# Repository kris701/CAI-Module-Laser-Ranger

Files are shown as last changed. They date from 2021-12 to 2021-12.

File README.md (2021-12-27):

# CAI-Module-Laser-Ranger
This is a project about making an extension module for my Snapmaker Original printer. This is also an extension to [another of my projects](https://github.com/kris701/CAI), and is directly connected to it. It is also designed to be mounted on my [toolhead extension project](https://github.com/kris701/SnapMaker-Toolhead-Extensions).
The purpose of this module is to making calibration of the Snapmaker Laser module easier, since it can be a bit of a pain to calibrate it every time you need to use it. Instead, this is a system where a little screen displays how far above the bed that the module is. This makes it a lot easier to calibrate is, as it removes the need to use that little calibration paper that comes with the printer.

<p align="center">
  
  
</p>

The system consists of a little OLED screen, a infrared proximity sensor and two buttons to calibrate it. The buttons can be held down, to move the little triangle in the display up or down. The last set calibration value is saved in the EEPROM of the Arduino Nano that controls it, so that its not lost when the power goes off.

<p align="center">
  
  
</p>

This then makes it so that you only really have to calibrate it once (with the calibration paper), and then you can just use the ranger module from there on out.

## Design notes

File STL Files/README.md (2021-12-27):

## Print Parts
### Screen Module
| |  |  |
|:---:|:---:|:---:|
| *Main Body* | *Lid* | *Screen Holder* |

### Sensor Module
| SensorModule_MainBody | SensorModule_Lid | SensorModule_Cover |
|:---:|:---:|:---:|
| *Main Body* | *Lid* | *Senspr Cover* |

The parts are put together with some M3 screws and bolts that i had.

## Printer settings

The config for a SnapMaker Original can be found under "Printing Config"

General config:

|Setting|Value|
|:---:|:---:|
| Layer Height |0.2mm |
| Top Thickness |0.8mm |
| Infil |35% |

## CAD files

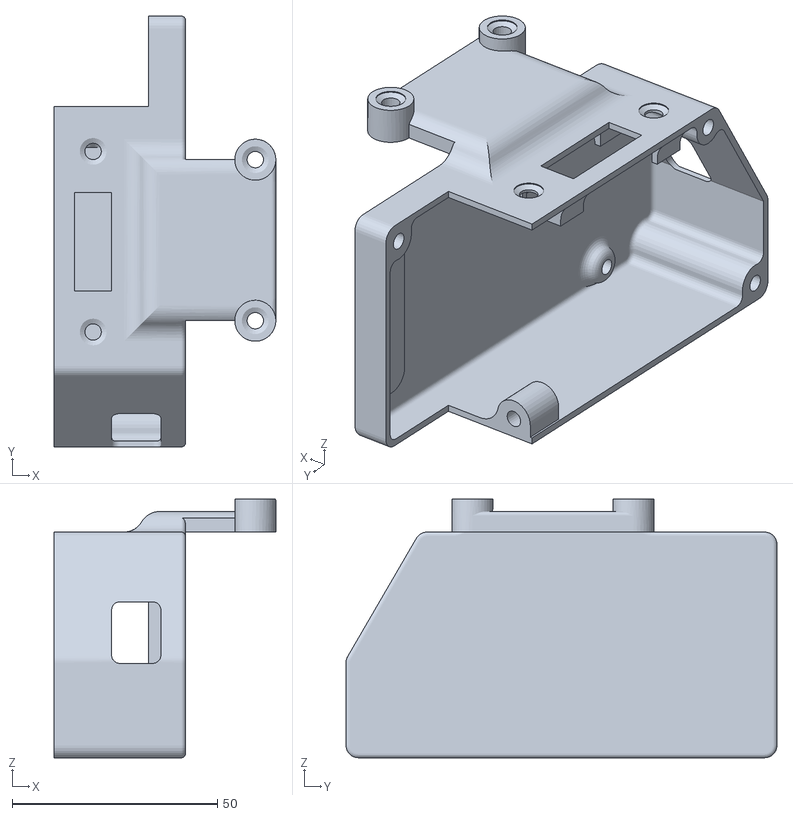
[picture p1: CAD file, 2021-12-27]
STL Files/ScreenModule/ScreenModule_MainBody.stl
54.0 x 105.0 x 63.0

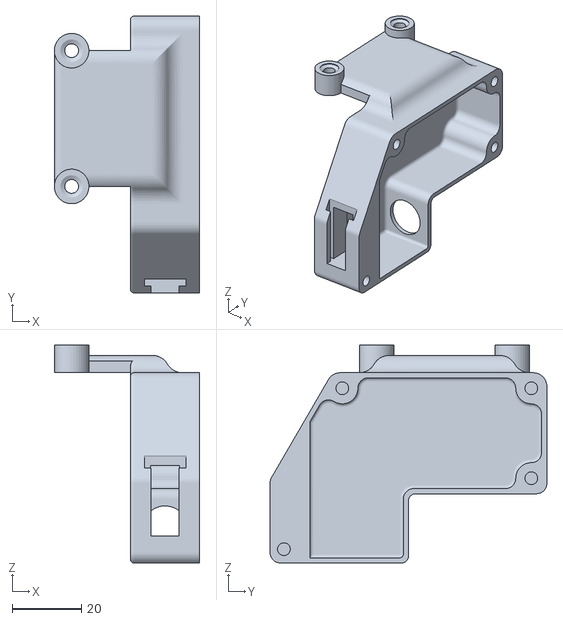
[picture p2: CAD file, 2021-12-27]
STL Files/SensorModule/SensorModule_MainBody.stl
42.0 x 80.0 x 63.0

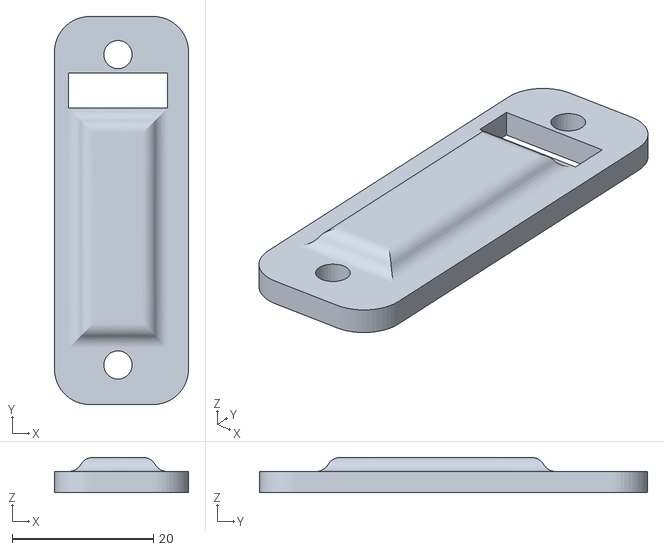
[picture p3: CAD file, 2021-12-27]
STL Files/ScreenModule/ScreenModule_ScreenHolder.stl
19.0 x 55.0 x 5.00

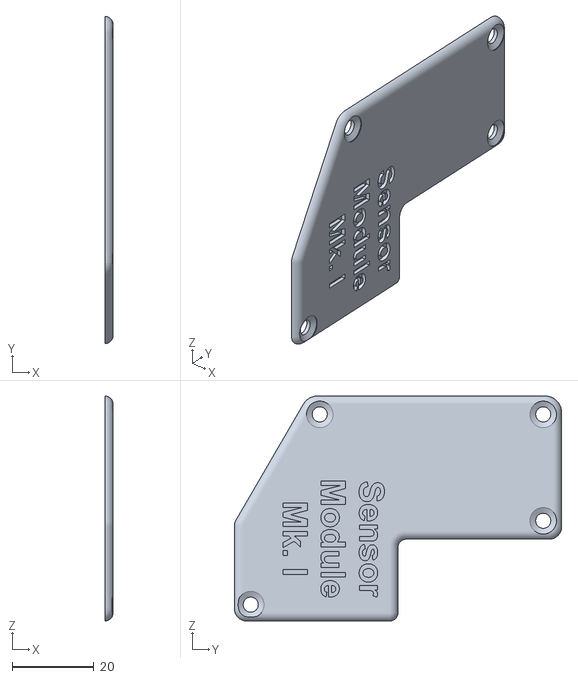
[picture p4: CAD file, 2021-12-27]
STL Files/SensorModule/SensorModule_Lid.stl
2.00 x 80.0 x 55.0

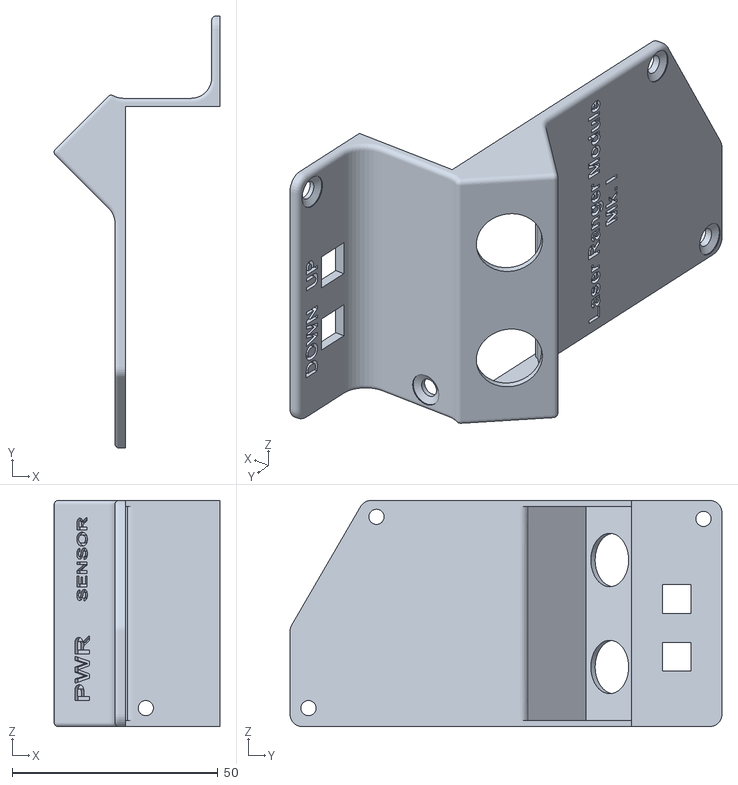
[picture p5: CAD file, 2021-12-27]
STL Files/ScreenModule/ScreenModule_Lid.stl
40.3 x 105.0 x 55.0

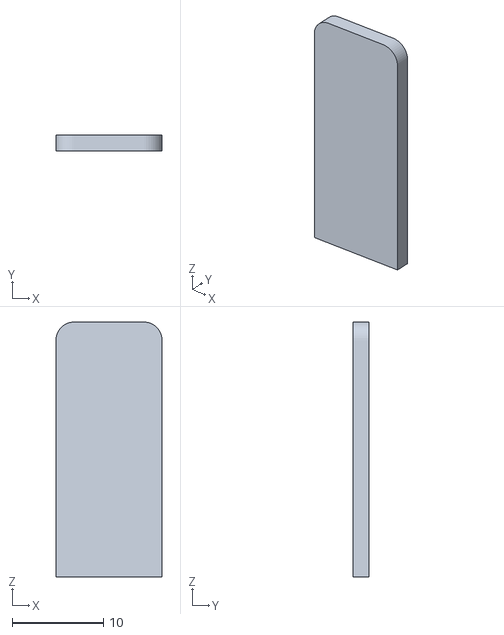
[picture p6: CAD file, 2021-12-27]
STL Files/SensorModule/SensorModule_Cover.stl
11.6 x 1.80 x 27.9

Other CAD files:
3D Models/RangerModuleCaseV1 v94.f3z

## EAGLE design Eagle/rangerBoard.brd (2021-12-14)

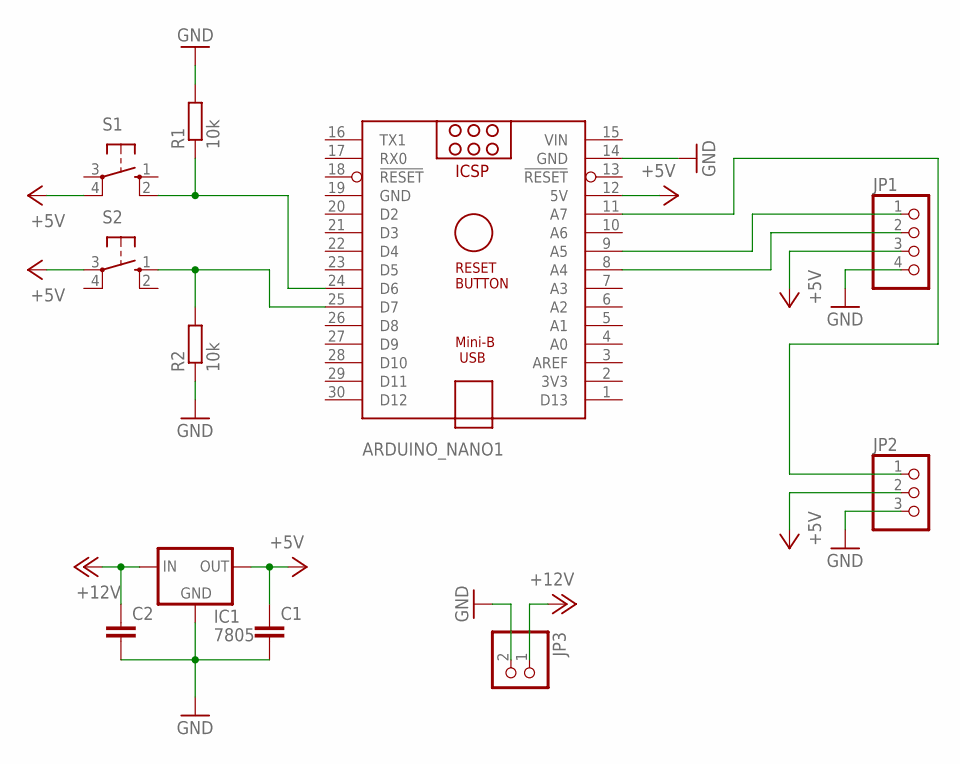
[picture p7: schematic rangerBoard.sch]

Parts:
ARDUINO_NANO1: ARDUINO_NANO
C1, C2: C5/7.2; C5B7.2
IC1: 7805; 78XXL
JP1: PINHD-1X4; 1X04
JP2: PINHD-1X3; 1X03
JP3: PINHD-1X2; 1X02
R1, R2: 10k; 0204/7
S1, S2: 10-XX; B3F-10XX

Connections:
+5V: ARDUINO_NANO1.12 (5V), C1.1, IC1.OUT, JP1.3, JP2.2, S1.4 (P1), S2.3
+12V: C2.1, IC1.IN, JP3.1
GND: ARDUINO_NANO1.14 (GND), ARDUINO_NANO1.19 (GND), C1.2, C2.2, IC1.GND, JP1.4, JP2.3, JP3.2, R1.2, R2.1
unnamed: ARDUINO_NANO1.24 (D6), R1.1, S1.2 (S1)
unnamed: ARDUINO_NANO1.25 (D7), R2.2, S2.1 (S)
unnamed: ARDUINO_NANO1.11 (A7), JP2.1
unnamed: ARDUINO_NANO1.8 (A4), JP1.2
unnamed: ARDUINO_NANO1.9 (A5), JP1.1
VIN: ARDUINO_NANO1.15 (VIN)

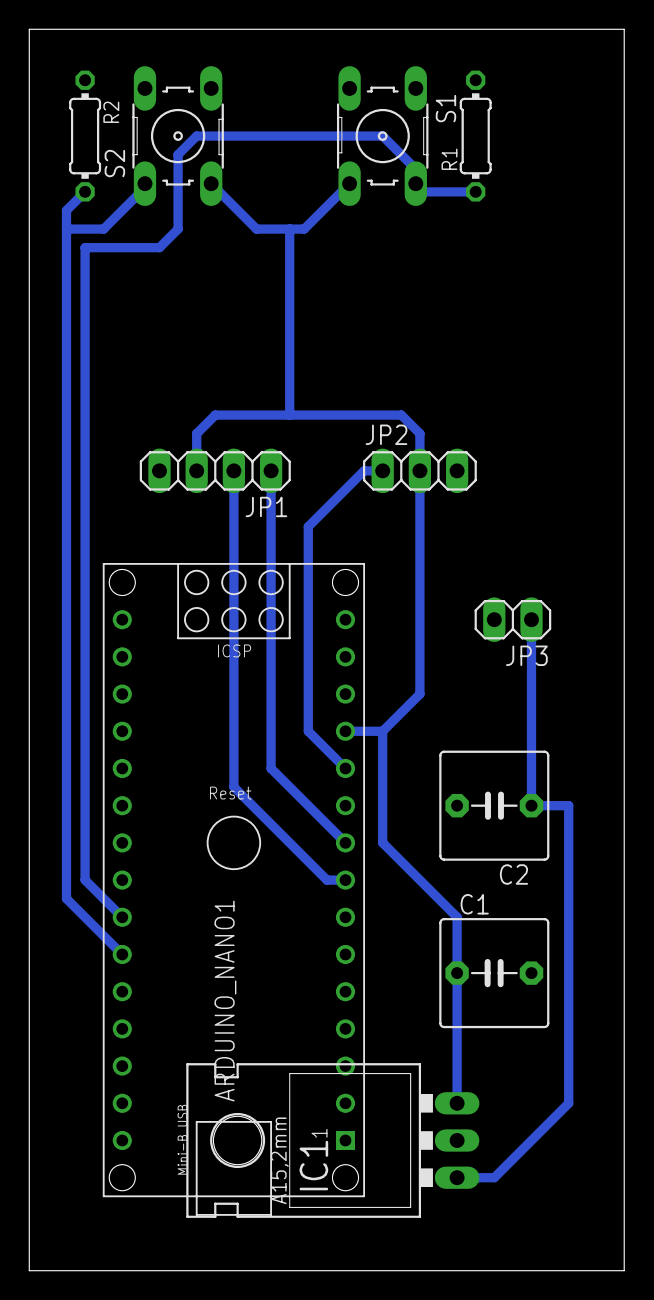
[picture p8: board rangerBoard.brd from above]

Board: 2 copper layers, 40.6 x 84.8 mm, 11 parts (0 on the bottom side), 8 nets.

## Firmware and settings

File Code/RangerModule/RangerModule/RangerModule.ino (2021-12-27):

#include "ScreenDriver.h"
#include <EEPROM.h>

ScreenDriver screenDriver = ScreenDriver();
#define sensorPin A7
#define sensorMaxValue 600
#define screenHeight 32
#define screenWidth 128

#define calUpPin 6
#define calDownPin 7
#define calAddr 0

int preHeight = 0;
int calValue = 0;

void setup() {
	pinMode(calUpPin, INPUT);
	pinMode(calDownPin, INPUT);
	screenDriver.startDisplay();
	screenDriver.clearDisplay();
	calValue = GetCalibrationValue();
	if (calValue > screenWidth)
		calValue = screenWidth;
}

void loop() {
	if (digitalRead(calUpPin) == 1) {
		calValue++;
		UpdateCalibration(calValue);
	}

	if (digitalRead(calDownPin) == 1) {
		calValue--;
		UpdateCalibration(calValue);
	}

	float reading = analogRead(sensorPin);
	int newWidth = (reading / sensorMaxValue) * screenWidth;
	Triangle calTri = { 0,15,calValue,25,screenWidth,15 };
	screenDriver.printTria(calTri, false, true);
	screenDriver.printText("Calibration",30,0);
	Rectangle rect = {0,30,newWidth,5};
	screenDriver.printRect(rect, true);
	preHeight = newWidth;
	delay(200);
}

void UpdateCalibration(int value) {
	if (value < 0)
		value = 0;
	if (value > screenWidth)
		value = screenWidth;
	EEPROM.write(calAddr, value);
}

int GetCalibrationValue() {
	return EEPROM.read(calAddr);
}

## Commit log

2021-12-14 Added first eagle drawings
    [rangerBoard.brd, rangerBoard.sch]
2021-12-27 * Updated code * Added models
    [RangerModuleCaseV1 v94.f3z]
2021-12-27 Added STL Files for printing
    [ScreenModule_Lid.stl, ScreenModule_MainBody.stl, ScreenModule_ScreenHolder.stl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]
2021-12-27 Added the printing config
